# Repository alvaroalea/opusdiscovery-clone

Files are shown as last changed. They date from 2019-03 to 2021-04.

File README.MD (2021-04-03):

# The Opus Discovery mini-clone Disk Interface for ZX Spectrum

UNDER LICENSE GPL Version 3

the schematic and PCB for this interfaz, make in KICAD
target is to have a PCB is less than 10x10cm so it's very cheap.

WARNING - THIS IS WORK IN PROGRESS - NOT TESTED

The Advantage of this interfaz over the original are:

- 4 Banks of ROM, so you can swap between original ROM and Quickdos, selectable by dip-switches, in the roms directory you can found it individually and one file ready to burn into a 28C256 flashrom.

- Included Fixed for +2A/+3, so can be used in any ZX Spectrum, selection by jumpers, compatibility with +2A/+3 is not yet tested.

- Reset Button

- Posibility of use crossed and plain floppy cable, and invert Drive 1 and Drive 2, very usefull if you have a Gotek and a real floppy.
With plain floppy cable you can use up to 4 drives.

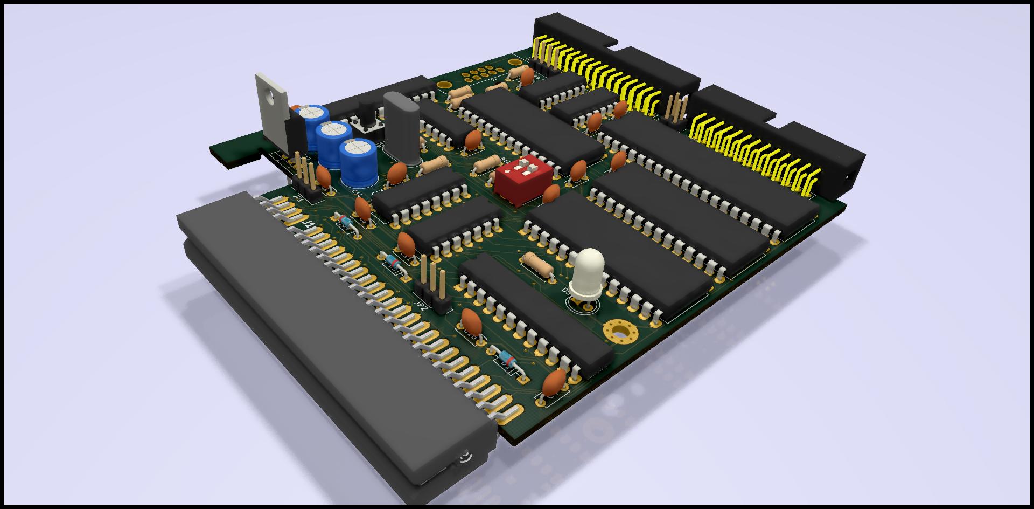
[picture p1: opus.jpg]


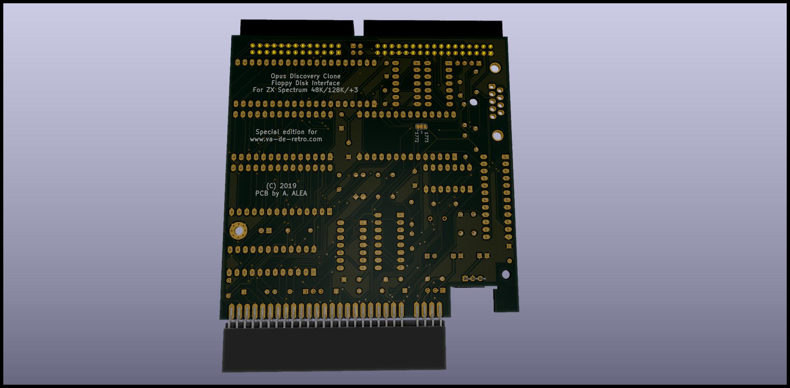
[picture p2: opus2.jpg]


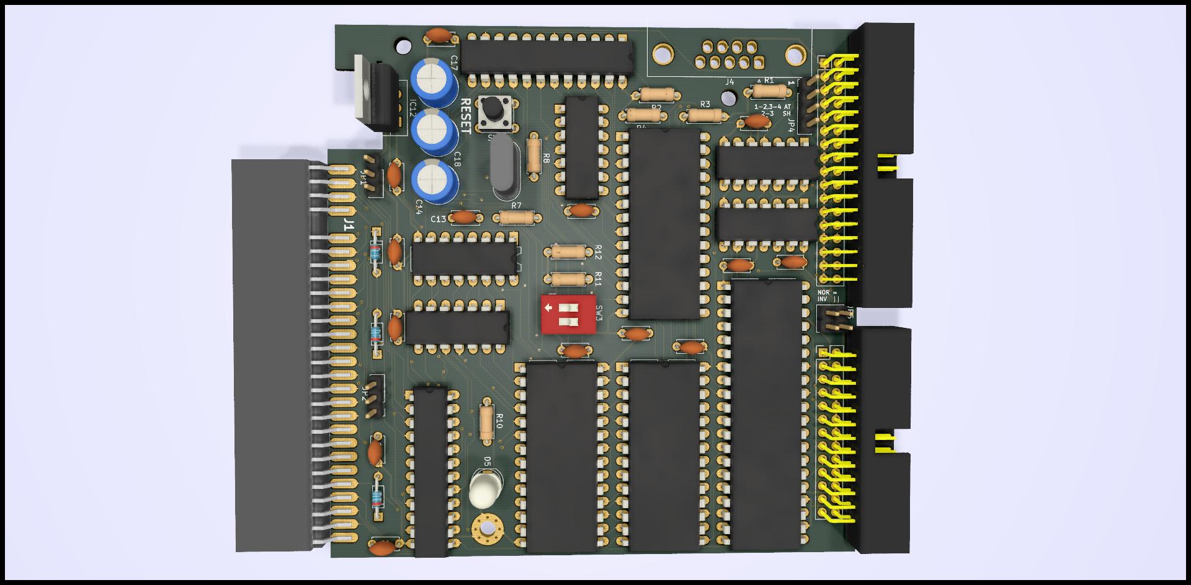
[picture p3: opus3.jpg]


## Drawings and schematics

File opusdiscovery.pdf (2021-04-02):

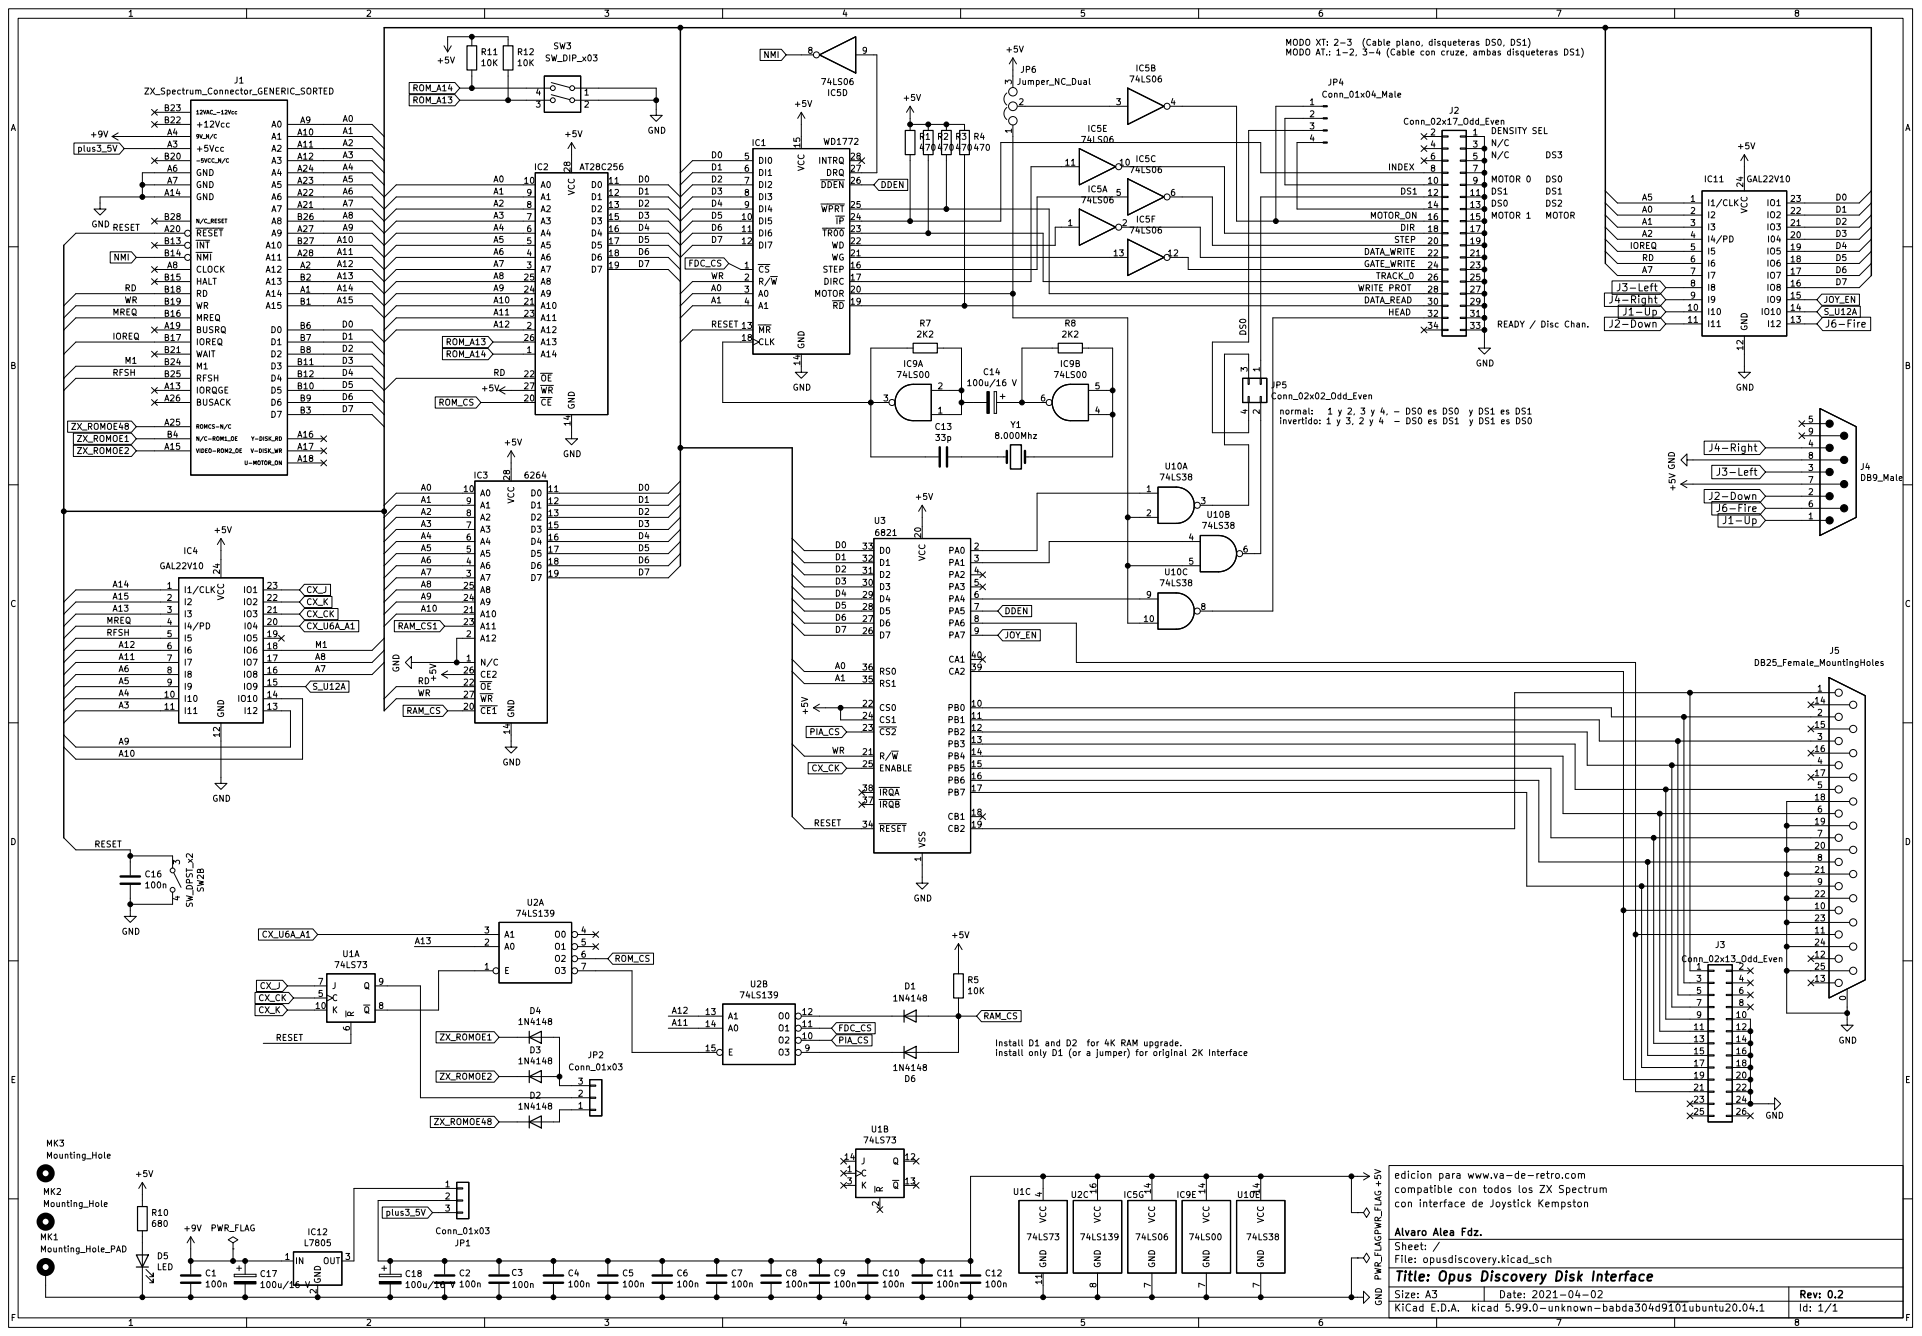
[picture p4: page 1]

DENSITY SEL MODO XT: 2-3 (Cable plano, disqueteras DS0, DS1)
MODO AT.: 1-2, 3-4 (Cable con cruze, ambas disqueteras DS1) GATE_WRITE

1 PB0 10 PB1 11 PB2 12 PB3 13 PB4 14 PB5 15 PB6 16 PB7 17 CB1 18 CB2 19 PA0 2 VCC 20 R/~W 21 CS0 22 ~CS2 23 CS1 24 ENABLE 25 D7 26 D6 27 D5 28 D4 29 PA1 3 D3 30 D2 31 D1 32 D0 33 ~RESET 34 RS1 35 RS0 36 ~IRQB 37 ~IRQA 38 CA2 39 PA2 4 CA1 40 PA3 5 PA4 6 PA5 7 PA6 8 PA7 9 U3

Install D1 and D2 for 4K RAM upgrade.
install only D1 (or a jumper) for original 2K Interface

edicion para www.va-de-retro.com
compatible con todos los ZX Spectrum
File: opusdiscovery.kicad_sch Sheet: / Alvaro Alea Fdz. con interface de Joystick Kempston

Id: 1/1 Title: Opus Discovery Disk Interface

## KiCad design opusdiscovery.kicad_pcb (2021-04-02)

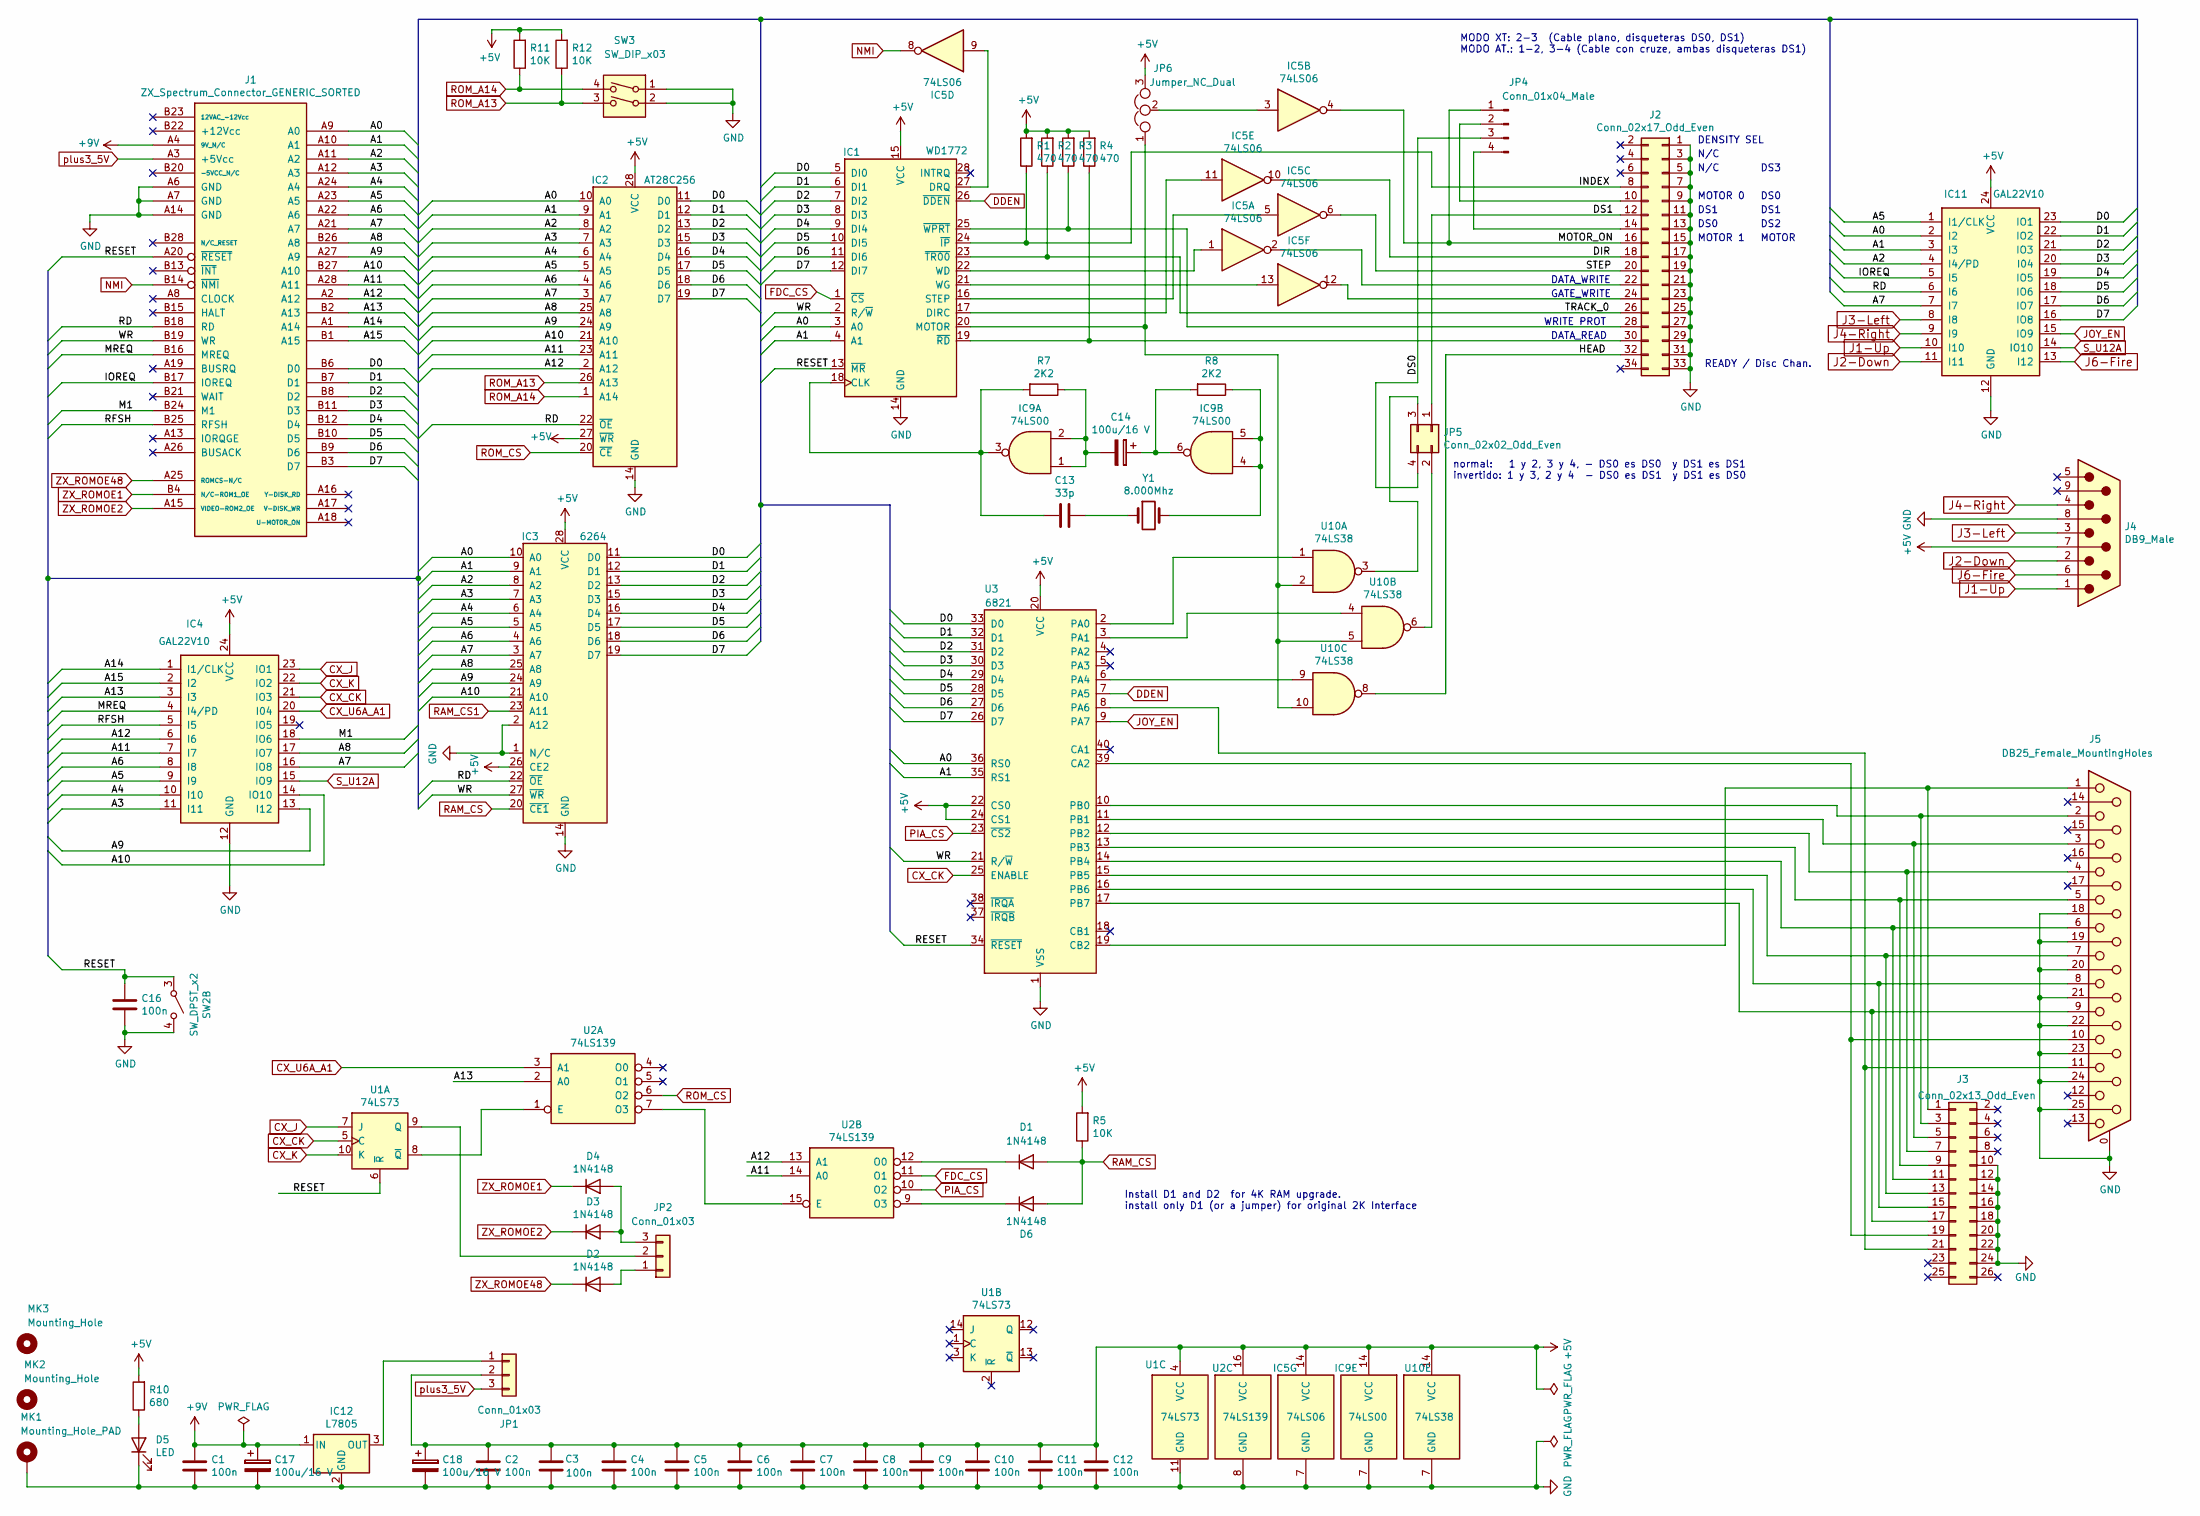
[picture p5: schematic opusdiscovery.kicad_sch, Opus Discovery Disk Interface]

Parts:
C1, C2, C3, C4, C5, C6, C7, C8, C9, C10, C11, C12, C16: 100n; C_Disc_D5.0mm_W2.5mm_P5.00mm
C13: 33p; C_Disc_D5.0mm_W2.5mm_P5.00mm
C14, C17, C18: 100u/16 V; CP_Radial_D7.5mm_P2.50mm
D1, D2, D3, D4, D6: 1N4148; D_DO-35_SOD27_P7.62mm_Horizontal
D5: LED; LED_D5.0mm
IC1: WD1772; DIP-28_W15.24mm_LongPads
IC2: AT28C256; DIP-28_W15.24mm_LongPads
IC3: 6264; DIP-28_W15.24mm_LongPads
IC4, IC11: GAL22V10; DIP-24_W7.62mm_LongPads
IC5: 74LS06; DIP-14_W7.62mm_LongPads
IC9: 74LS00; DIP-14_W7.62mm_LongPads
IC12: L7805; TO-220-3_Vertical
J1: ZX_Spectrum_Connector_GENERIC_SORTED; ZX_CONN
J2: Conn_02x17_Odd_Even; PinHeader_2x17_P2.54mm_Vertical
J3: Conn_02x13_Odd_Even; PinHeader_2x13_P2.54mm_Vertical
J4: DB9_Male; DSUB-9_Male_Horizontal_P2.77x2.84mm_EdgePinOffset4.94mm_Hou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
J5: DB25_Female_MountingHoles; DSUB-25_Female_Horizontal_P2.77x2.84mm_EdgePinOffset4.94mm_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
JP1, JP2: Conn_01x03; PinHeader_1x03_P2.54mm_Vertical
JP4: Conn_01x04_Male; PinHeader_1x04_P2.54mm_Vertical
JP5: Conn_02x02_Odd_Even; PinHeader_2x02_P2.54mm_Vertical
JP6: Jumper_NC_Dual; SolderJumper-3_P1.3mm_Bridged12_RoundedPad1.0x1.5mm
MK1: Mounting_Hole_PAD; MountingHole_3mm_Pad_Via
MK2, MK3: Mounting_Hole; MountingHole_3mm
R1, R2, R3, R4: 470; R_Axial_DIN0207_L6.3mm_D2.5mm_P7.62mm_Horizontal
R5, R11, R12: 10K; R_Axial_DIN0207_L6.3mm_D2.5mm_P7.62mm_Horizontal
R7, R8: 2K2; R_Axial_DIN0207_L6.3mm_D2.5mm_P7.62mm_Horizontal
R10: 680; R_Axial_DIN0207_L6.3mm_D2.5mm_P7.62mm_Horizontal
SW2: SW_DPST_x2; SW_TH_Tactile_Omron_B3F-10xx
SW3: SW_DIP_x03; SW_DIP_SPSTx02_Slide_6.7x6.64mm_W7.62mm_P2.54mm_LowProfile
U1: 74LS73; DIP-14_W7.62mm_LongPads
U2: 74LS139; DIP-16_W7.62mm_LongPads
U3: 6821; DIP-40_W15.24mm_LongPads
U10: 74LS38; DIP-14_W7.62mm_LongPads
Y1: 8.000Mhz; Crystal_HC18-U_Vertical

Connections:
+5V: C2.2, C3.2, C4.2, C5.2, C6.2, C7.2, C8.2, C9.2, C10.2, C11.2, C12.2, C18.1, IC1.15 (VCC), IC2.27 (~WR), IC2.28 (VCC), IC3.26 (CE2), IC3.28 (VCC), IC4.24 (VCC), IC5.14 (VCC), IC9.14 (VCC), IC11.24 (VCC), J4.7, JP1.2, JP6.3, R1.2, R2.2, R3.2, R4.2, R5.2, R10.2, R11.2, R12.2, U1.4 (VCC), U2.16 (VCC), U3.20 (VCC), U3.22 (CS0), U3.24 (CS1), U10.14 (VCC)
+9V: C1.2, C17.1, IC12.1 (IN), J1.A4 (9V_N/C)
/A0: IC1.3 (A0), IC2.10 (A0), IC3.10 (A0), IC11.2 (I2), J1.A9 (A0), U3.36 (RS0)
/A1: IC1.4 (A1), IC2.9 (A1), IC3.9 (A1), IC11.3 (I3), J1.A10 (A1), U3.35 (RS1)
/A2: IC2.8 (A2), IC3.8 (A2), IC11.4 (I4/PD), J1.A11 (A2)
/A3: IC2.7 (A3), IC3.7 (A3), IC4.11 (I11), J1.A12 (A3)
/A4: IC2.6 (A4), IC3.6 (A4), IC4.10 (I10), J1.A24 (A4)
/A5: IC2.5 (A5), IC3.5 (A5), IC4.9 (I9), IC11.1 (I1/CLK), J1.A23 (A5)
/A6: IC2.4 (A6), IC3.4 (A6), IC4.8 (I8), J1.A22 (A6)
/A7: IC2.3 (A7), IC3.3 (A7), IC4.16 (IO8), IC11.7 (I7), J1.A21 (A7)
/A8: IC2.25 (A8), IC3.25 (A8), IC4.17 (IO7), J1.B26 (A8)
/A9: IC2.24 (A9), IC3.24 (A9), IC4.13 (I12), J1.A27 (A9)
/A10: IC2.21 (A10), IC3.21 (A10), IC4.14 (IO10), J1.B27 (A10)
/A11: IC2.23 (A11), IC4.7 (I7), J1.A28 (A11), U2.14 (A0)
/A12: IC2.2 (A12), IC4.6 (I6), J1.A2 (A12), U2.13 (A1)
/A13: IC4.3 (I3), J1.B2 (A13), U2.2 (A0)
/A14: IC4.1 (I1/CLK), J1.A1 (A14)
/A15: IC4.2 (I2), J1.B1 (A15)
/D0: IC1.5 (DI0), IC2.11 (D0), IC3.11 (D0), IC11.23 (IO1), J1.B6 (D0), U3.33 (D0)
/D1: IC1.6 (DI1), IC2.12 (D1), IC3.12 (D1), IC11.22 (IO2), J1.B7 (D1), U3.32 (D1)
/D2: IC1.7 (DI2), IC2.13 (D2), IC3.13 (D2), IC11.21 (IO3), J1.B8 (D2), U3.31 (D2)
/D3: IC1.8 (DI3), IC2.15 (D3), IC3.15 (D3), IC11.20 (I04), J1.B11 (D3), U3.30 (D3)
/D4: IC1.9 (DI4), IC2.16 (D4), IC3.16 (D4), IC11.19 (IO5), J1.B12 (D4), U3.29 (D4)
/D5: IC1.10 (DI5), IC2.17 (D5), IC3.17 (D5), IC11.18 (IO6), J1.B10 (D5), U3.28 (D5)
/D6: IC1.11 (DI6), IC2.18 (D6), IC3.18 (D6), IC11.17 (IO7), J1.B9 (D6), U3.27 (D6)
/D7: IC1.12 (DI7), IC2.19 (D7), IC3.19 (D7), IC11.16 (IO8), J1.B3 (D7), U3.26 (D7)
/DIR: IC5.10, J2.18
/DS0: JP4.3, JP5.4
/DS1: J2.12, JP5.1
/HEAD: J2.32, U10.8
/INDEX: IC1.24 (~IP), J2.8, R1.1
/IOREQ: IC11.5 (I5), J1.B17 (IOREQ)
/M1: IC4.18 (IO6), J1.B24 (M1)
/MOTOR_ON: IC5.4, J2.16, JP4.1
/MREQ: IC4.4 (I4/PD), J1.B16 (MREQ)
/RD: IC2.22 (~OE), IC3.22 (~OE), IC11.6 (I6), J1.B18 (RD)
/RESET: C16.2, IC1.13 (~MR), J1.A20 (~RESET), SW2.3 (A), U1.6 (~R), U3.34 (~RESET)
/RFSH: IC4.5 (I5), J1.B25 (RFSH)
/STEP: IC5.6, J2.20
/TRACK_0: IC1.23 (~TR00), J2.26, R2.1
/WR: IC1.2 (R/~W), IC3.27 (~WR), J1.B19 (WR), U3.21 (R/~W)
CX_CK: IC4.21 (IO3), U1.5 (C), U3.25 (ENABLE)
CX_J: IC4.23 (IO1), U1.7 (J)
CX_K: IC4.22 (IO2), U1.10 (K)
CX_U6A_A1: IC4.20 (I04), U2.3 (A1)
DDEN: IC1.26 (~DDEN), U3.7 (PA5)
FDC_CS: IC1.1 (~CS), U2.11 (O1)
GND: C1.1, C2.1, C3.1, C4.1, C5.1, C6.1, C7.1, C8.1, C9.1, C10.1, C11.1, C12.1, C16.1, C17.2, C18.2, D5.1 (K), IC1.14 (GND), IC2.14 (GND), IC3.1 (N/C), IC3.2 (A12), IC3.14 (GND), IC4.12 (GND), IC5.7 (GND), IC9.7 (GND), IC11.12 (GND), IC12.2 (GND), J1.A6 (GND), J1.A7 (GND), J1.A14 (GND), J2.1, J2.3, J2.5, J2.7, J2.9, J2.11, J2.13, J2.15, J2.17, J2.19, J2.21, J2.23, J2.25, J2.27, J2.29, J2.31, J2.33, J3.10, J3.12, J3.14, J3.16, J3.18, J3.20, J3.22, J3.24, J4.8, J5.0 (PAD), J5.18, J5.19, J5.20, J5.21, J5.22, J5.23, J5.24, J5.25, MK1.1, SW2.4 (B), SW3.1, SW3.2, U1.11 (GND), U2.8 (GND), U3.1 (VSS), U10.7 (GND)
J1-Up: IC11.10 (I10), J4.1
J2-Down: IC11.11 (I11), J4.2
J3-Left: IC11.8 (I8), J4.3
J4-Right: IC11.9 (I9), J4.4
J6-Fire: IC11.13 (I12), J4.6
JOY_EN: IC11.15 (IO9), U3.9 (PA7)
NMI: IC5.8, J1.B14 (~NMI)
unnamed: C13.1, Y1.1
unnamed: C13.2, IC1.18 (CLK), IC9.3, R7.2
unnamed: C14.1, IC9.6, R8.2
unnamed: C14.2, IC9.1, IC9.2, R7.1
unnamed: D2.2 (A), JP2.1
unnamed: D3.2 (A), D4.2 (A), JP2.3
unnamed: D5.2 (A), R10.1
unnamed: IC1.16 (STEP), IC5.5
unnamed: IC1.17 (DIRC), IC5.11
unnamed: IC1.19 (~RD), J2.30, R4.1
unnamed: IC1.20 (MOTOR), JP6.1, U10.2, U10.5, U10.10
unnamed: IC1.21 (WG), IC5.13
unnamed: IC1.22 (WD), IC5.1
unnamed: IC1.25 (~WPRT), J2.28, R3.1
unnamed: IC1.27 (DRQ), IC5.9
unnamed: IC5.2, J2.22
unnamed: IC5.3, JP6.2
unnamed: IC5.12, J2.24
unnamed: IC9.4, IC9.5, R8.1, Y1.2
unnamed: IC12.3 (OUT), JP1.1
unnamed: J2.10, JP4.2
unnamed: J2.14, JP4.4
unnamed: J3.1, J5.1, U3.19 (CB2)
unnamed: J3.3, J5.2, U3.10 (PB0)
unnamed: J3.5, J5.3, U3.11 (PB1)
unnamed: J3.7, J5.4, U3.12 (PB2)
unnamed: J3.9, J5.5, U3.13 (PB3)
unnamed: J3.11, J5.6, U3.14 (PB4)
unnamed: J3.13, J5.7, U3.15 (PB5)
unnamed: J3.15, J5.8, U3.16 (PB6)
unnamed: J3.17, J5.9, U3.17 (PB7)
unnamed: J3.19, J5.10, U3.39 (CA2)
unnamed: J3.21, J5.11, U3.8 (PA6)
unnamed: JP2.2, U1.9 (Q)
unnamed: JP5.2, U10.6
unnamed: JP5.3, U10.3
unnamed: U1.8 (~Q), U2.1 (E)
unnamed: U2.7 (O3), U2.15 (E)
unnamed: U3.2 (PA0), U10.1
unnamed: U3.3 (PA1), U10.4
unnamed: U3.6 (PA4), U10.9
PIA_CS: U2.10 (O2), U3.23 (~CS2)
RAM_CS: D1.2 (A), D6.2 (A), IC3.20 (~CE1), R5.1
RAM_CS2: D6.1 (K), U2.9 (O3)
ROM_A13: IC2.26 (A13), R12.1, SW3.3
ROM_A14: IC2.1 (A14), R11.1, SW3.4
ROM_CS: IC2.20 (~CE), U2.6 (O2)
S_U12A: IC4.15 (IO9), IC11.14 (IO10)
ZX_ROMOE1: D4.1 (K), J1.B4 (N/C-ROM1_OE)
ZX_ROMOE2: D3.1 (K), J1.A15 (VIDEO-ROM2_OE)
ZX_ROMOE48: D2.1 (K), J1.A25 (ROMCS-N/C)
plus3_5V: J1.A3 (+5Vcc), JP1.3

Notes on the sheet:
Install D1 and D2 for 4K RAM upgrade. install only D1 (or a jumper) for original 2K Interface
normal: 1 y 2, 3 y 4, - DS0 es DS0 y DS1 es DS1 invertido: 1 y 3, 2 y 4 - DS0 es DS1 y DS1 es DS0
MODO XT: 2-3 (Cable plano, disqueteras DS0, DS1) MODO AT.: 1-2, 3-4 (Cable con cruze, ambas disqueteras DS1)
WRITE PROT
DATA_WRITE
GATE_WRITE
DATA_READ
DENSITY SEL
N/C
MOTOR 0
DS1
DS0
MOTOR 1
READY / Disc Chan.
DS3
DS0
DS2
MOTOR

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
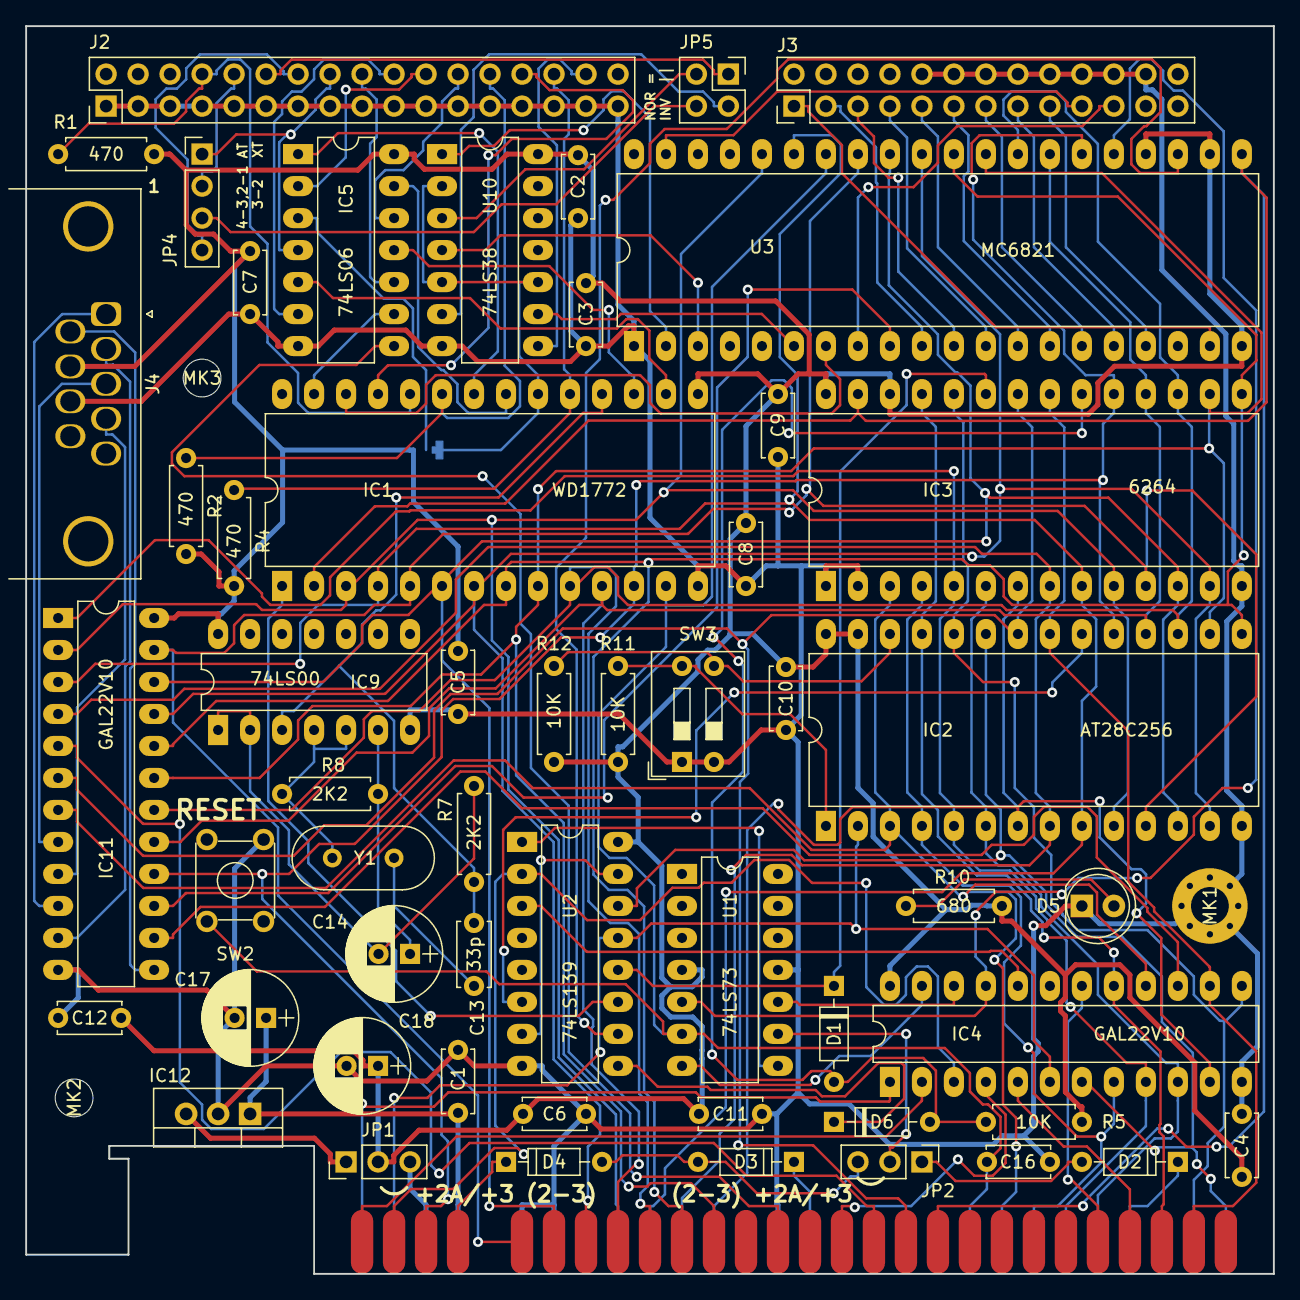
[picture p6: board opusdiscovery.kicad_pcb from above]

Board: 2 copper layers, 99.1 x 99.1 mm, 59 parts (1 on the bottom side), 108 nets.

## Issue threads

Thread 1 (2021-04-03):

Reordenar las patillas de IC04

alvaroalea, 2021-04-03:
Actualmente IC04 tiene que ser una GAL22V10, pero solo utiliza 4 pines como salida, se podria utilizar tambien una 20V8 si se intercambiasen algunos pines que se utilizan como salidas y en el 20V8 son entradas unicamente

arleybls, 2025-08-05:
Hi Alvaro. Despite this is there anything unfinished? I am willing to give it a shot and test the interface.

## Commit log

2021-04-02 upgrade to kicad 6 and include roms directory
    [opusdiscovery.kicad_pcb, opusdiscovery.kicad_sch, opusdiscovery.sch]
2021-04-02 update gal equations
    [opusdiscovery.kicad_sch]

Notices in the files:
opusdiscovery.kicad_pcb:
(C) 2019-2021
